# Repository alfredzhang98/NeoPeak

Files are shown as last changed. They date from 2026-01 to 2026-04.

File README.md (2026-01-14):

## 说明

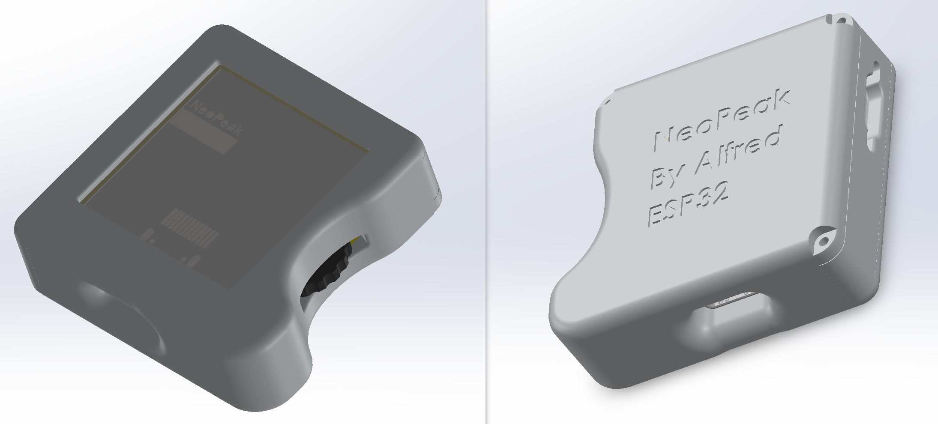
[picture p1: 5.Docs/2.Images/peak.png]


NeoPeak 是基于 [Peak](https://github.com/peng-zhihui/Peak) 项目的硬件和软件优化版本。

关于 Peak 项目本身的详细介绍，请参考 [Peak 项目的 README](https://github.com/peng-zhihui/Peak/blob/main/README.md)。

本项目记录了以下优化工作：

> 原 Peak 项目基于雅特力 AT32F403ACGU7 主控芯片。NeoPeak 将其迁移到 **ESP32 平台**，提供更好的性能、WiFi/BLE 连接能力和生态支持，同时对硬件和固件进行优化改进。

## 1. 硬件改进

### 芯片选择

原 Peak 项目使用雅特力 AT32F403ACGU7 主控。关于各芯片的详细对比分析，请参考 [Peak 项目的硬件部分](https://github.com/peng-zhihui/Peak/blob/main/README.md)。

NeoPeak 选择使用 **ESP32-PICO-V3-02** 作为主控芯片。

### 传感器和执行器

NeoPeak 的主要硬件改进包括：

- **更高性能的 IMU**：升级了惯性测量单元，提供更精准的运动和姿态检测 ICM-42688-P。
- **电动机震动反馈**：添加电动机震动功能，增强用户交互体验

## 2. 固件改进

关于软件架构设计（LVGL、页面调度、消息框架等框架层的详细说明），请参考 [Peak 项目的固件部分](https://github.com/peng-zhihui/Peak/blob/main/README.md)。

NeoPeak 基于这些框架在 ESP32 平台上的移植和优化经验，主要改进包括内存管理优化和 ESP32 平台特性适配等。

## 参考链接 

* [Peak](https://github.com/peng-zhihui/Peak)
* [LVGL](https://github.com/lvgl/lvgl)
* [Bing Maps Tile System](https://docs.microsoft.com/en-us/bingmaps/articles/bing-maps-tile-system?redirectedfrom=MSDN)
* [IOS ViewController](https://developer.apple.com/documentation/uikit/uiviewcontroller)
* [ESP32之软件SPI驱动及SPI、HSPI和VSPI的理解](https://blog.csdn.net/jdsnpgxj/article/details/100013357)
* [ESP32 程序的内存模型](https://zhuanlan.zhihu.com/p/345915256)
* [Heap Memory Allocation](https://docs.espressif.com/projects/esp-idf/en/latest/esp32/api-reference/system/mem_alloc.html)
* [Error: region `dram0_0_seg' overflowed by 31632 bytes](https://www.esp32.com/viewtopic.php?t=7131)
* [[ESP32] ld: region `dram0_0_seg’ overflowed by 156768 bytes](https://community.platformio.org/t/esp32-ld-region-dram0-0-seg-overflowed-by-156768-bytes/18753)

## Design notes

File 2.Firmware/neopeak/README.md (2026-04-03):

# NeoPeak Firmware

ESP-IDF firmware for the NeoPeak board. Uses board/HAL/drivers/services layering with a message bus for data flow.

## Build and flash
- ESP-IDF: 5.5.2
- Configure pins and options in Kconfig (`menuconfig`).
- Build/flash using standard ESP-IDF workflow.

## Structure
- main: entry point (`app_main`)
- components/board: board_init and board-level wiring
- components/hal_board: hardware abstraction (replace for new boards)
- components/drivers: device drivers built on HAL
- components/services: app logic and data flow (message bus, IMU, power, encoder)

## Notes
- `board_init()` centralizes all CONFIG_ usage and passes configs into drivers/services.
- Services communicate via `message_bus` topics.

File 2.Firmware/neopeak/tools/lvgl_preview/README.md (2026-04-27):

# NeoPeak LVGL Preview

This folder builds the NeoPeak LVGL UI as a Windows desktop preview using SDL2.
The preview and the ESP-IDF firmware share `components/ui/imu_cube_ui.cpp`.

## Install once

Install these tools on Windows:

- Git
- CMake
- Ninja
- Visual Studio Build Tools with the C++ desktop workload
- vcpkg

Install SDL2 with vcpkg:

```powershell
cd C:\
git clone https://github.com/microsoft/vcpkg.git
cd C:\vcpkg
.\bootstrap-vcpkg.bat
.\vcpkg install sdl2:x64-windows
```

If vcpkg is not installed at `C:\vcpkg`, set `VCPKG_ROOT` before building:

```powershell
$env:VCPKG_ROOT = "D:\Tools\vcpkg"
```

## Build

From the repo root:

```powershell
.\tools\lvgl_preview\build_preview.ps1
```

Or manually:

```powershell
cmake -S tools/lvgl_preview -B build/lvgl_preview -G Ninja `
  -DCMAKE_TOOLCHAIN_FILE=C:/vcpkg/scripts/buildsystems/vcpkg.cmake

cmake --build build/lvgl_preview
```

## Run

```powershell
.\tools\lvgl_preview\run_preview.ps1
```

The preview opens a 240x240 LVGL window and drives the IMU cube with fake roll
and pitch values.

## Firmware build

The ESP-IDF firmware uses the same UI source through the `ui` component. Build
the firmware normally after ESP-IDF is installed:

```powershell
& D:\SDKs\.espressif\v6.0\esp-idf\export.ps1
idf.py build
```

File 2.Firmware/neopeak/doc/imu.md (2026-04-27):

# IMU 姿态估计

ICM-42688-P (6 轴) → Madgwick 滤波 → quaternion → cube 渲染。

## 信号链

```
ICM-42688-P (200 Hz ODR)
  └ 片上 3 阶 LPF, BW = ODR/10 ≈ 20 Hz
        │
        ▼  poll @ 100 Hz (10 ms)
imu_service::imu_task
  ├ remap_imu()      chip body → screen frame: (+X, -Y, -Z)
  ├ bias 校准        60 连续静止样本 (gmag < 12°/s)，运动则清零
  ├ initial_q        校准结束时由 accel 均值算 shortest-arc q
  ├ madgwick_step()  β = 0.015, dt 由 timestamp 算
  └ publish MSG_TOPIC_IMU (q, calib_percent, bias)
        │
        ▼
display_service::on_imu_msg → ui_app_handle_imu → imu_cube_ui_update
imu_cube_ui state machine: Calibrating → AwaitConfirm → Running
```

## 关键参数

| 参数 | 值 | 文件 |
|---|---|---|
| ODR | 200 Hz | [icm42688p.cpp:276](../components/drivers/imu/icm42688p.cpp#L276) |
| 片上 LPF | 3 阶, ODR/10 (20 Hz) | [imu_service.cpp:411-415](../components/services/imu/imu_service.cpp#L411) |
| polling | 100 Hz (10 ms) | sdkconfig: `CONFIG_IMU_SAMPLE_PERIOD_MS=10` |
| Madgwick gain β_p (proportional) | 2.0 | [imu_service.cpp:21-31](../components/services/imu/imu_service.cpp#L21) |
| Accel 软 LPF α | 0.5 (~14 ms tau) | [imu_service.cpp:34](../components/services/imu/imu_service.cpp#L34) |
| 校准样本数 | 60 (~0.6 s) | [imu_service.cpp:33](../components/services/imu/imu_service.cpp#L33) |
| 校准静止阈值 | 12°/s | [imu_service.cpp:34](../components/services/imu/imu_service.cpp#L34) |
| Axis remap | `(+X, -Y, -Z)` 对 accel + gyro | [imu_service.cpp:48-58](../components/services/imu/imu_service.cpp#L48) |

## Madgwick 6 轴融合

状态：单位 quaternion `q = (w, x, y, z)`，body → world 旋转。

每步：
1. **gyro 积分**：`q̇ = ½ q ⊗ ω_body`（ω 是 bias 修正后的角速度）
2. **accel 校正（proportional 形式）**：用 (q^T)·(0,0,1) 与 a_norm 的残差 ∇f 做"非归一化"梯度下降——`q̇_corr = -β_p · ∇f`，**校正幅度直接和误差成正比**（不是论文的归一化形式）
3. **更新**：`q ← q + (q̇_gyro + q̇_corr) · dt`，归一化

无 Euler 中间状态 → 无万向锁、无 atan2 跳变。

**为什么用 proportional 形式（不是论文原版）**：

- 归一化版校正速度恒为 β rad/s，与误差大小无关。结果：β 大→静止时被噪声放大成抖动；β 小→大误差恢复线性慢。两者天生互斥
- 非归一化版校正 ∝ 误差。误差大时快、近真值时几乎不动 → 同时解决"快速恢复"和"静止不抖"
- β_p 的物理意义：1/τ 时间常数。β_p=2.0 → τ=0.5s，90% 恢复 ~1.15s

## 启动校准

```cpp
if (gmag_dps < 12.0f) {
    accumulate gyro/accel
    if (samples == 60) {
        s_gyro_bias = mean(gyro_accum)
        s_q         = initial_q_from_accel(mean(accel_accum))
        s_bias_ready = true
    }
} else {
    reset accumulator   // 运动检测到就重新数
}
```

`initial_q_from_accel` 用 shortest-arc 公式从重力方向直接算 q，避免 Madgwick 从 identity 慢慢收敛 30 秒。

## UI 状态机

[imu_cube_ui.cpp](../components/ui/imu_cube_ui.cpp)：

| 状态 | 显示 | 进入条件 |
|---|---|---|
| `Calibrating` | "CALIBRATING" + 进度条 + 提示 | 进页面 / 收到 calib_percent < 100 |
| `AwaitConfirm` | "CALIBRATED" + 三轴 bias 数值 | 收到 calib_percent == 100 |
| `Running` | cube + q0..q3 标签 | 单击 |

## 生命周期

| 事件 | 行为 |
|---|---|
| 进 IMU 页 | sensor 上电 + reset_filter_state + bias 重新校准 |
| Running 单击 | `imu_cube_ui_reset()` 把当前 q 当新零点 |
| BACK 单击 / 双击 | sensor 断电，下次进入再校准 |

bias 不缓存——每次进入都重新校准（处理温度漂移）。

## 抗运动加速度门控

`madgwick_step()` 仅在 `|a| ∈ [0.65, 1.35] g` 时应用 accel 校正——超出说明手在大幅运动，accel 不只读到重力（含线性加速度），**只信 gyro 积分**，不污染 q。回到带内立即恢复 proportional 校正。

不再需要"恢复期"或"真静止"特殊档——proportional 形式的指数衰减天然完成：误差大→拉得快、误差小→自动慢→不抖。

效果：剧烈晃动后只要把表放下、或停手，**100~200ms 内** β 跳到 0.5，roll/pitch 直接被锁回真重力方向。

## 已知 trade-off

- **每次进 IMU 页等 ~1s**：换温度自适应；可改成"后台一直跑"方案省这 1s 但 bias 会随戴久了温度变化偏移
- **β = 0.015 偏低**：静止稳，但若 gyro bias 长期飘 (温度变化 30°C+)，yaw 修正会偏慢——属于"每次重新校准"覆盖的场景
- **远端 yaw 漂移**：6 轴无磁力计无法绑定真北，长时间 yaw 必然漂；通过 reset 按钮人工修正
- **持续大动作时 roll/pitch 会临时跟不上**：抗运动门控期间只走 gyro，gyro bias 会有累积；动作停下、|a| 回到 1g 时 Madgwick 重新拉回——观感是"动作大时稍慢、停下后快速归位"

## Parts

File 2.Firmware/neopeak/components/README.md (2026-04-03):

组件目录（components）项目架构总览

本目录用于沉淀板级抽象、驱动与服务/应用层的模块化实现，形成清晰的分层结构，便于复用与扩展。

目录分层说明（components 下的功能目录）：

- board
	- 板级抽象层（Board Support），对硬件资源进行统一封装与配置。
	- 提供板卡初始化、引脚映射、外设复用等能力，向上屏蔽具体硬件差异。

- hal_board (HAL)
	- 硬件抽象层（Hardware Abstraction Layer），对底层外设访问进行再抽象。
	- 向上提供统一的硬件访问接口，向下对接 drivers 与底层 SDK。

- drivers
	- 设备驱动层，包含 SPI/I2C/GPIO/PWM 等外设驱动与器件驱动。
	- 负责与硬件寄存器或底层 SDK 交互，提供稳定的设备访问接口。

- services
	- 服务与应用层，包含通信状态机、算法以及应用逻辑等。
	- 通过 message bus 进行数据发布与订阅，组织业务流程。

文档规范：

每一个目录下都应包含一个 README/MD 文档，用于说明：

- 该目录的目标与职责边界
- 允许放置的模块类型与开发指导
- 对外接口说明（如有）
- 典型用法与示例

本 README 用于总结整体架构与分层职责，作为 components 目录的总览说明。

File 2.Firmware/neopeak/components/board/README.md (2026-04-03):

# board

## 目的
板级抽象层（Board Support），对硬件资源进行统一封装与配置，向上屏蔽板卡差异。

## 这里放什么
- 板卡初始化流程与默认配置
- 引脚映射、外设复用配置
- 板级资源表（GPIO、总线、供电、时钟）
- 统一管理 CONFIG_ 并向 drivers/services 传递配置

## 开发指导
- 不直接访问寄存器或具体外设驱动，避免与 drivers/hal_board 重复。
- 只做与“板子”相关的差异化处理。
- 对外暴露清晰的初始化与资源查询接口。

## 示例
- board_init()
- board_init_*_configs()
- board_get_display_pins()

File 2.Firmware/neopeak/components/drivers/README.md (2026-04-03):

# drivers

## 目的
设备驱动层，直接操作外设或器件，提供稳定的设备访问接口。

## 这里放什么
- SPI/I2C/UART/GPIO/PWM 等外设驱动
- 具体器件驱动（传感器、屏幕、编码器等）

## 开发指导
- 封装底层 SDK/寄存器细节，对外暴露简洁 API。
- 通过 HAL 访问 I2C/PWM/GPIO 等能力，避免与板级逻辑耦合。
- 不包含业务逻辑，保持可复用与可测试。
- 需要时提供 mock 或测试桩。

## 示例
- imu42688p_begin()
- imu42688p_read_raw()
- buzzer_start()
- motor_pwm_shake()

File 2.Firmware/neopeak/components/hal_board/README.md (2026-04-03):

# HAL (hal_board)

## 目的
硬件抽象层（Hardware Abstraction Layer），对底层外设访问进行再抽象，向上提供统一接口。

## 换板子提示
当需要更换板子时，优先只修改 HAL 的实现（.cpp）。
上层 services/board 依赖 HAL 接口，不应该直接依赖底层 SDK 或寄存器。
保持 HAL 接口稳定，可以让业务逻辑在不同板子间复用。

## 这里放什么
- 面向功能的硬件抽象接口（如 hal_i2c/hal_spi/hal_gpio）
- 统一的设备访问模型（初始化、读写、错误码）

## 开发指导
- 向下依赖底层 SDK，向上被 board/services 使用。
- 不做业务逻辑，仅提供稳定硬件能力。
- 保持接口稳定与可移植。

## 示例
- hal_i2c_master_bus_init()
- hal_i2c_master_device_write_read()
- hal_gpio_set_level()
- hal_input_power_init()
- hal_encoder_init()
- hal_pwm_timer_init()

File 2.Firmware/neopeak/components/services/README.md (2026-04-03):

# services

## 目的
服务与应用层，包含通信状态机、算法与应用逻辑等。

## 这里放什么
- 通信状态机与协议适配
- 算法与策略模块
- 应用层流程与业务逻辑

## 目录划分
- core: 通用能力（消息总线、提示音谱子/播放器等）
- imu: 传感器采样、融合与姿态计算
- power: 电源策略、按键状态机、开关机流程
- display: 显示线程、页面切换与 UI 状态机
- comm: 通信协议、连接状态机与数据同步（含编码器事件）

## 开发指导
- 组合使用 message bus/HAL/drivers 能力。
- 业务逻辑清晰分层，避免下沉到驱动层。
- 通过接口隔离与单元测试保证可维护性。

## 示例
- encoder_service_start()
- imu_service_start()
- power_service_start()

## 提示音模块（Tone）
- 文件：core/tone_map.h / core/tone_player.h/.cpp / core/tone_music.h/.cpp / core/tone_utils.h/.cpp
- 提供提示音谱子与播放器逻辑，便于电源管理或业务层触发音效。
- 典型流程：
	1) 通过 `tone_music_get()` 获取曲目
	2) `TonePlayer::SetCallback()` 绑定蜂鸣器输出
	3) 周期调用 `TonePlayer::Update()` 播放

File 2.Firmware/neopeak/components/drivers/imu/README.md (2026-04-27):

# imu

ICM-42688-P device driver layer.

This driver only talks to the sensor through `hal_i2c_device_t`, so board code
owns the ESP-IDF v6 I2C master bus/device creation and pin mapping.

Hardware notes from DS-000347 v1.6:

- I2C address is `0x68` when `AP_AD0` is low and `0x69` when `AP_AD0` is high.
- `WHO_AM_I` is `0x47`.
- Pin 7 is `RESV` and should be connected to GND.
- Pin 12 `AP_CS` should be connected to VDDIO for I2C/I3C operation.
- I2C lines are open drain and need pull-up resistors.

Typical flow:

1. Create an ESP-IDF v6 I2C master bus with `hal_i2c_master_bus_init()`.
2. Add the IMU address with `hal_i2c_master_device_add()`.
3. Call `icm42688p_config_default()` and `icm42688p_begin()`.
4. Read data with `icm42688p_read_raw()` or `icm42688p_read()`.

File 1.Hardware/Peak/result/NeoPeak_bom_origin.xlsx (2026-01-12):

Comment | Designator | Footprint | LibRef | Quantity
AN2051-245 | ANT1 | ANTC5020X127N | AN2051-245 | 1
10uF | C1, C6, C11 | C0402_L | C | 3
0.1uF | C2, C4, C7, C8, C12, C14, C15 | C0402_L | C | 7
1uF | C3, C10, C13 | C0402_L | C | 3
4.7uF | C5, C9 | C0402_L | C | 2
1N5819WS | D1, D2, D3 | SOD-323 | 1N5819 | 3
ESP32-PICO-V3-02-ES | IC1 | ESP32PICOV302ES | ESP32-PICO-V3-02-ES | 1
ICM-42688-P | IC2 | IIM42352 | ICM-42688-P | 1
ME6211A33M3G-N | IC3 | SOT95P280X145-3N | ME6211A33M3G-N | 1
CON-6P | JP1 | FPC0.5-WT-6P | Header 6 | 1
G | LED1 | LED0402_G | LED | 1
HDR-1X2 | Motor1 | HDR1.27-LI-2P | Header 2 | 1
BC847BVC-7 | Q1 | SOT563-6 | BC847BVC-7 | 1
AO3400A | Q2, Q4, Q5, Q6 | SOT23-3 | AO3400A | 4
AO3401A | Q3 | SOT23-3 | AO3401A | 1
10k | R1, R4, R5, R7, R8, R9, R10, R15, R21, R22, R23, R24, R26, R27, R29, R31, R33, R34 | R0402_L | R | 18
0 | R2, R25 | R0402_L | R | 2
200 | R3 | R0402_L | R | 1
12k | R6, R11 | R0402_L | R | 2
5.1k | R12, R14 | R0402_L | R | 2
10 | R13 | R0402_L | R | 1
100k | R16, R17 | R0402_L | R | 2
2k | R18 | R0402_L | R | 1
1k | R19 | R0402_L | R | 1
20k | R20, R28 | R0402_L | R | 2
0(NC) | R30 | R0402_L | R | 1
100 | R32 | R0402_L | R | 1
LCD-240x240 | S1 | LCD-240x240-FlUSH-154 | LCD-240x240 | 1
Rotary Encoder | SW1 | SIQ-02FVS3 | Rotary Encoder | 1
TF | TF1 | TF-SOCKET | TF卡座 | 1
CP2102 | U1 | QFN-28 | CP2102 | 1
MCP73831T | U2 | SOT23-5 | MCP73831T | 1
DET402 | U3 | DET402 | DET402 | 1
Type-C | USB1 | Type-C-TOP | USB-Type-C-TOP | 1

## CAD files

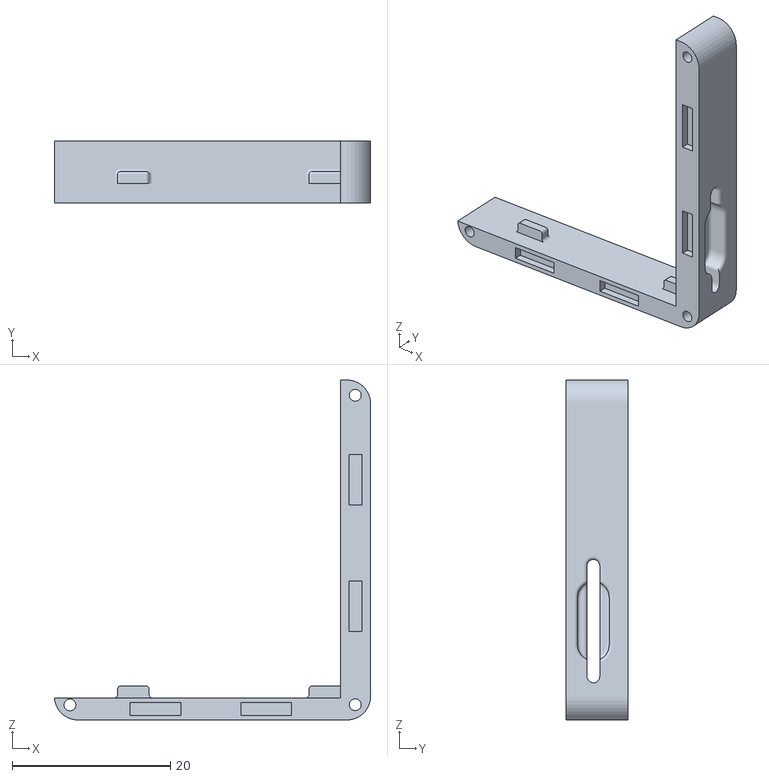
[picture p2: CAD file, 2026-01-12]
4.Model/base_side.STL
40.0 x 7.90 x 43.0

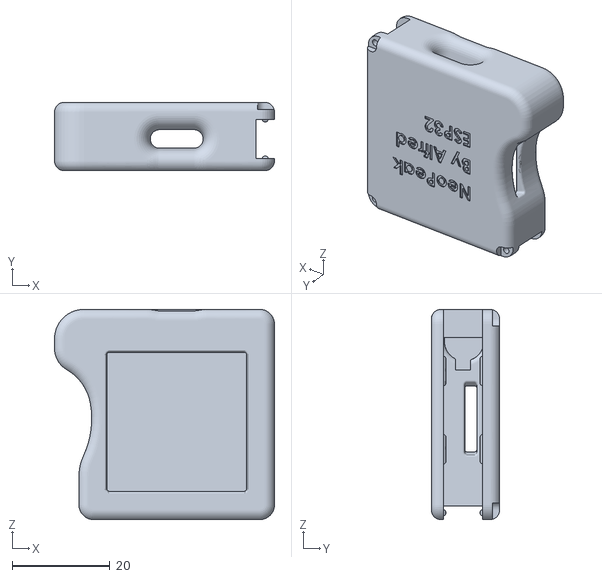
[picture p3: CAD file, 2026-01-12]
4.Model/base.STL
45.0 x 14.0 x 43.0

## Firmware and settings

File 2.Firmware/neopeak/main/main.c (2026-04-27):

/*
 * SPDX-FileCopyrightText: 2010-2022 Espressif Systems (Shanghai) CO LTD
 *
 * SPDX-License-Identifier: CC0-1.0
 */

#include "esp_log.h"
#include "freertos/FreeRTOS.h"
#include "freertos/task.h"

#include "board_init.h"
#include "display_service.h"
#include "imu_service.h"
#include "sdkconfig.h"

static const char *TAG = "main";

void app_main(void)
{
    board_init();

    esp_err_t err = display_service_start();
    if (err != ESP_OK) {
        ESP_LOGE(TAG, "display service start failed: %s", esp_err_to_name(err));
    }

    const imu_service_config_t imu_cfg = {
        .sda_pin = CONFIG_MCU_SDA_PIN,
        .scl_pin = CONFIG_MCU_SCL_PIN,
        .i2c_addr = CONFIG_IMU_I2C_ADDR,
        .i2c_clk_hz = CONFIG_IMU_I2C_HZ,
        .sample_period_ms = CONFIG_IMU_SAMPLE_PERIOD_MS,
    };
    err = imu_service_start(&imu_cfg);
    if (err != ESP_OK) {
        ESP_LOGE(TAG, "imu service start failed: %s", esp_err_to_name(err));
    }

    while (true) {
        vTaskDelay(pdMS_TO_TICKS(1000));
    }
}

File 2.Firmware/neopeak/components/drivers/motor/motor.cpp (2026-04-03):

#include "motor.h"

#include "freertos/FreeRTOS.h"
#include "freertos/task.h"
#include "hal_pwm.h"

static bool s_connected = true;
static bool s_initialized = false;
static int32_t s_duration_ms = 0;
static uint32_t s_duty = 0;
static int s_gpio_num = -1;
static ledc_mode_t s_speed_mode = LEDC_LOW_SPEED_MODE;
static ledc_timer_t s_timer = LEDC_TIMER_1;
static ledc_channel_t s_channel = LEDC_CHANNEL_1;
static ledc_timer_bit_t s_duty_resolution = LEDC_TIMER_10_BIT;
static uint32_t s_pwm_freq_hz = 200;

static uint32_t motor_level_to_duty(motor_intensity_t intensity)
{
    const uint32_t max_duty = (1u << s_duty_resolution) - 1u;
    if ((int)intensity <= 0) {
        return 0;
    }
    if ((int)intensity > 10) {
        intensity = MOTOR_INTENSITY_10;
    }

    return (max_duty * (uint32_t)intensity) / 10u;
}

static void motor_task(void *arg)
{
    (void)arg;
    while (true) {
        if (s_duration_ms > 0) {
            if (s_duty > 0) {
                hal_pwm_set_duty(s_speed_mode, s_channel, s_duty);
                hal_pwm_update_duty(s_speed_mode, s_channel);
            } else {
                hal_pwm_set_duty(s_speed_mode, s_channel, 0);
                hal_pwm_update_duty(s_speed_mode, s_channel);
            }

            vTaskDelay(pdMS_TO_TICKS(s_duration_ms));

            hal_pwm_set_duty(s_speed_mode, s_channel, 0);
            hal_pwm_update_duty(s_speed_mode, s_channel);

            s_duration_ms = 0;
        }

        vTaskDelay(pdMS_TO_TICKS(50));
    }
}

void pwm_motor_init(const motor_pwm_config_t *cfg)
{
    if (cfg == nullptr) {
        return;
    }

    s_gpio_num = cfg->gpio_num;
    s_speed_mode = cfg->speed_mode;
    s_timer = cfg->timer_num;
    s_channel = cfg->channel;
    s_duty_resolution = cfg->duty_resolution;
    s_pwm_freq_hz = cfg->pwm_freq_hz;

    if (s_gpio_num < 0) {
        s_connected = false;
        return;
    }

    hal_pwm_timer_cfg_t timer_cfg = {
        .speed_mode = s_speed_mode,
        .timer_num = s_timer,
        .duty_resolution = s_duty_resolution,
        .freq_hz = s_pwm_freq_hz,
        .clk_cfg = LEDC_AUTO_CLK,
    };
    hal_pwm_timer_init(&timer_cfg);

    hal_pwm_channel_cfg_t ch_cfg = {
        .gpio_num = s_gpio_num,
        .speed_mode = s_speed_mode,
        .channel = s_channel,
        .timer_sel = s_timer,
        .duty = 0,
        .hpoint = 0,
    };
    hal_pwm_channel_init(&ch_cfg);

    s_initialized = true;
    xTaskCreate(motor_task, "motor_task", 2048, NULL, 4, NULL);
}

void pwm_motor_shake(int32_t duration_ms, motor_intensity_t intensity)
{
    if (!s_connected || !s_initialized) {
        return;
    }

    if (duration_ms <= 0) {
        s_duration_ms = 0;
        s_duty = 0;
        hal_pwm_set_duty(s_speed_mode, s_channel, 0);
        hal_pwm_update_duty(s_speed_mode, s_channel);
        return;
    }

    s_duty = motor_level_to_duty(intensity);
    s_duration_ms = duration_ms;
}

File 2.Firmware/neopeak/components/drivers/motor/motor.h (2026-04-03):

#pragma once

#include <stdbool.h>
#include <stdint.h>

#include "driver/ledc.h"

#ifdef __cplusplus
extern "C" {
#endif

typedef enum {
    MOTOR_INTENSITY_1 = 1,
    MOTOR_INTENSITY_2 = 2,
    MOTOR_INTENSITY_3 = 3,
    MOTOR_INTENSITY_4 = 4,
    MOTOR_INTENSITY_5 = 5,
    MOTOR_INTENSITY_6 = 6,
    MOTOR_INTENSITY_7 = 7,
    MOTOR_INTENSITY_8 = 8,
    MOTOR_INTENSITY_9 = 9,
    MOTOR_INTENSITY_10 = 10,
} motor_intensity_t;

typedef struct {
    int gpio_num;
    ledc_mode_t speed_mode;
    ledc_timer_t timer_num;
    ledc_channel_t channel;
    ledc_timer_bit_t duty_resolution;
    uint32_t pwm_freq_hz;
} motor_pwm_config_t;

void pwm_motor_init(const motor_pwm_config_t *cfg);
void pwm_motor_shake(int32_t duration_ms, motor_intensity_t intensity);

#ifdef __cplusplus
}
#endif

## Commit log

2026-01-12 update hardware
    [Main.SchDoc, NeoPeak_bom_origin.xlsx, Peak.PrjPCB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]
2026-04-26 Refactor firmware: remove IMU, migrate to ESP-IDF v6.0, fix charge debounce
    - Remove all ICM-42688-P driver and imu_service code
    - Fix ledc_channel_config_t and i2c_master_bus_config_t for ESP-IDF v6.0 new fields
    - Add debounce (500ms) to charge detection to prevent vibration/buzzer spam on noisy pin
    - Fix flash size config: 2MB → 8MB to match actual hardware
    - Relocate audio (tone_*) files from services/core to drivers/audio
    - Relocate encoder_service from services/comm to services/input
    - Add feedback_service as standalone component
    - Fix PWR_MGMT0 staged init and DATA_RDY polling in IMU driver (before removal)
    [board_init.cpp, encoder_service.cpp, feedback_service.cpp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]
2026-04-27 Add IMU page with Madgwick filter, ST7789 driver, LVGL UI shell
    Brings the firmware from a bare-board boot to a usable interactive device:
    - Display: ST7789 init via esp_lcd at SPI mode 3, on-chip 20 Hz UI low-pass.
    display_service exposes blank() so the screen goes dark the moment a
    shutdown long-press is detected, before the buzzer jingle finishes.
    - IMU: ICM-42688-P driver + Madgwick 6-axis filter at 100 Hz with
    startup gyro-bias calibration, accel-seeded initial quaternion to skip
    the slow Madgwick convergence, and a single axis-remap macro block.
    See doc/imu.md for the algorithm summary.
    - UI: monochrome + orange accent design (Home / IMU / Settings / Info),
    encoder rotate/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
    [buzzer.cpp, display_service.cpp, encoder_service.cpp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]
2026-04-27 Tune IMU filter and round out IMU page UX
    - Switch Madgwick to non-normalized (proportional) form: correction
    scales with attitude error, giving fast recovery after motion stops
    while keeping the cube rock-still at rest. Drops the multi-tier
    beta + static-detection state machine in favor of a single gain.
    - Add a soft accel low-pass on top of the chip filter (~14 ms tau) to
    push the noise floor down further.
    - Widen the accel trust band to [0.65, 1.35] g so ordinary handling
    still gets gravity correction.
    - Settings: add a YAW on/off row, persist across IMU page entries.
    - imu_cube_ui: swing-twist quaternion strip when yaw is disabled,
    consume_click on the calibration overlay con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
    [display_service.cpp, imu_service.cpp]
